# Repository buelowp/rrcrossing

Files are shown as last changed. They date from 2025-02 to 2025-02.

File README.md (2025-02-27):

# In track IR sensor for realistic crossing signals
This is a HW project based on a RPi Pico which will monitor 4 track sensors to determine which way a train is going, and then operate flashers and gates for one crossing. This actually works really well so far. But it needs more testing.

See a video in action at (https://youtu.be/GjpNI9cR6WQ)

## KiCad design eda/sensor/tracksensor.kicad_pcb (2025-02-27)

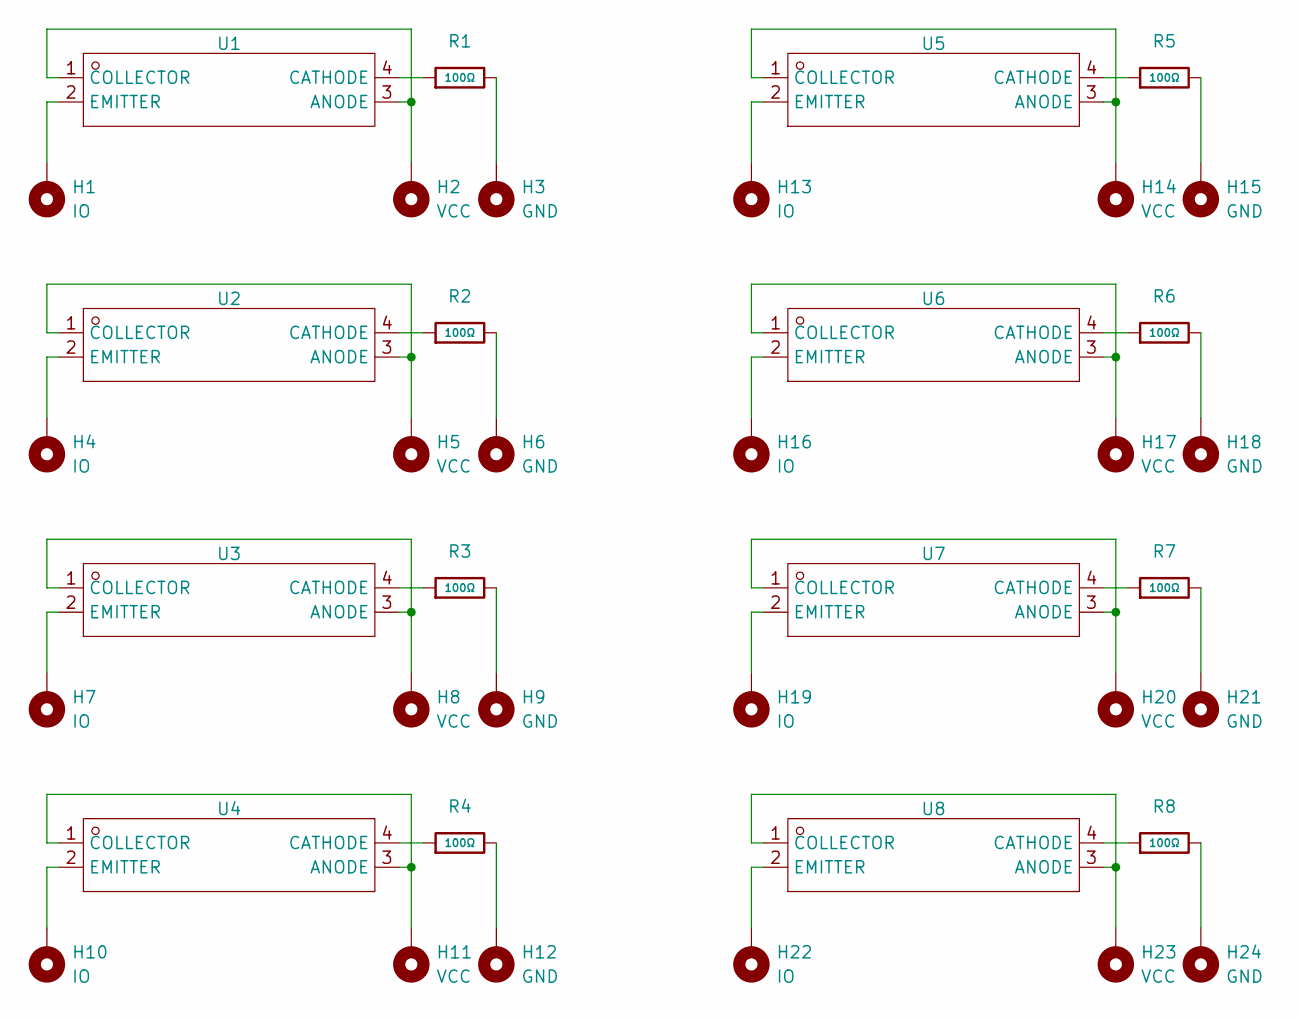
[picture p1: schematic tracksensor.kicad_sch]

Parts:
H1, H4, H7, H10, H13, H16, H19, H22: IO; TestPoint_Pad_1.5x1.5mm
H2, H5, H8, H11, H14, H17, H20, H23: VCC; TestPoint_Pad_1.5x1.5mm
H3, H6, H9, H12, H15, H18, H21, H24: GND; TestPoint_Pad_1.5x1.5mm
R1, R2, R3, R4, R5, R6, R7, R8: 100Ω; R_0402; Overload Voltage (Max) 50V; Tolerance ±1%; Part 0402WGF1000TCE; LCSC C25076
U1, U2, U3, U4, U5, U6, U7, U8: OPTO-SMD-4_ITR1204SR10A; Manufacturer Part ITR1204SR10A/TR(BY); LCSC Part Name 光电开关(ITR)

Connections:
unnamed: H3.1, R1.2
unnamed: H6.1, R2.2
unnamed: H9.1, R3.2
unnamed: H12.1, R4.2
unnamed: H15.1, R5.2
unnamed: H18.1, R6.2
unnamed: H21.1, R7.2
unnamed: H24.1, R8.2
unnamed: H2.1, U1.1 (COLLECTOR), U1.3 (ANODE)
unnamed: R1.1, U1.4 (CATHODE)
unnamed: H1.1, U1.2 (EMITTER)
unnamed: H5.1, U2.1 (COLLECTOR), U2.3 (ANODE)
unnamed: R2.1, U2.4 (CATHODE)
unnamed: H4.1, U2.2 (EMITTER)
unnamed: H8.1, U3.1 (COLLECTOR), U3.3 (ANODE)
unnamed: R3.1, U3.4 (CATHODE)
unnamed: H7.1, U3.2 (EMITTER)
unnamed: H11.1, U4.1 (COLLECTOR), U4.3 (ANODE)
unnamed: R4.1, U4.4 (CATHODE)
unnamed: H10.1, U4.2 (EMITTER)
unnamed: H14.1, U5.1 (COLLECTOR), U5.3 (ANODE)
unnamed: R5.1, U5.4 (CATHODE)
unnamed: H13.1, U5.2 (EMITTER)
unnamed: H17.1, U6.1 (COLLECTOR), U6.3 (ANODE)
unnamed: R6.1, U6.4 (CATHODE)
unnamed: H16.1, U6.2 (EMITTER)
unnamed: H20.1, U7.1 (COLLECTOR), U7.3 (ANODE)
unnamed: R7.1, U7.4 (CATHODE)
unnamed: H19.1, U7.2 (EMITTER)
unnamed: H23.1, U8.1 (COLLECTOR), U8.3 (ANODE)
unnamed: R8.1, U8.4 (CATHODE)
unnamed: H22.1, U8.2 (EMITTER)

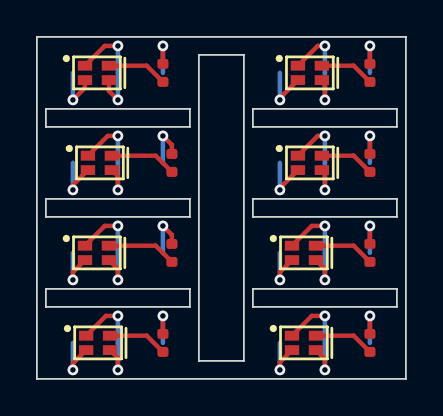
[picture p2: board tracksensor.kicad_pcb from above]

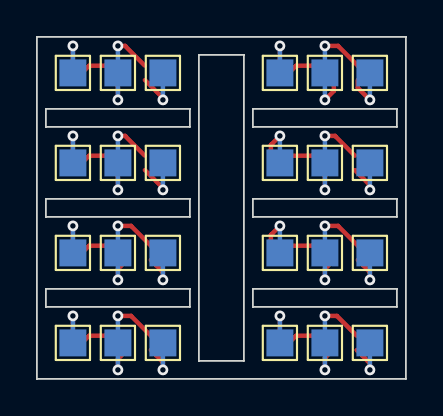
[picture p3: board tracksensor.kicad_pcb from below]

Board: 2 copper layers, 20.5 x 19.0 mm, 40 parts (24 on the bottom side), 32 nets.

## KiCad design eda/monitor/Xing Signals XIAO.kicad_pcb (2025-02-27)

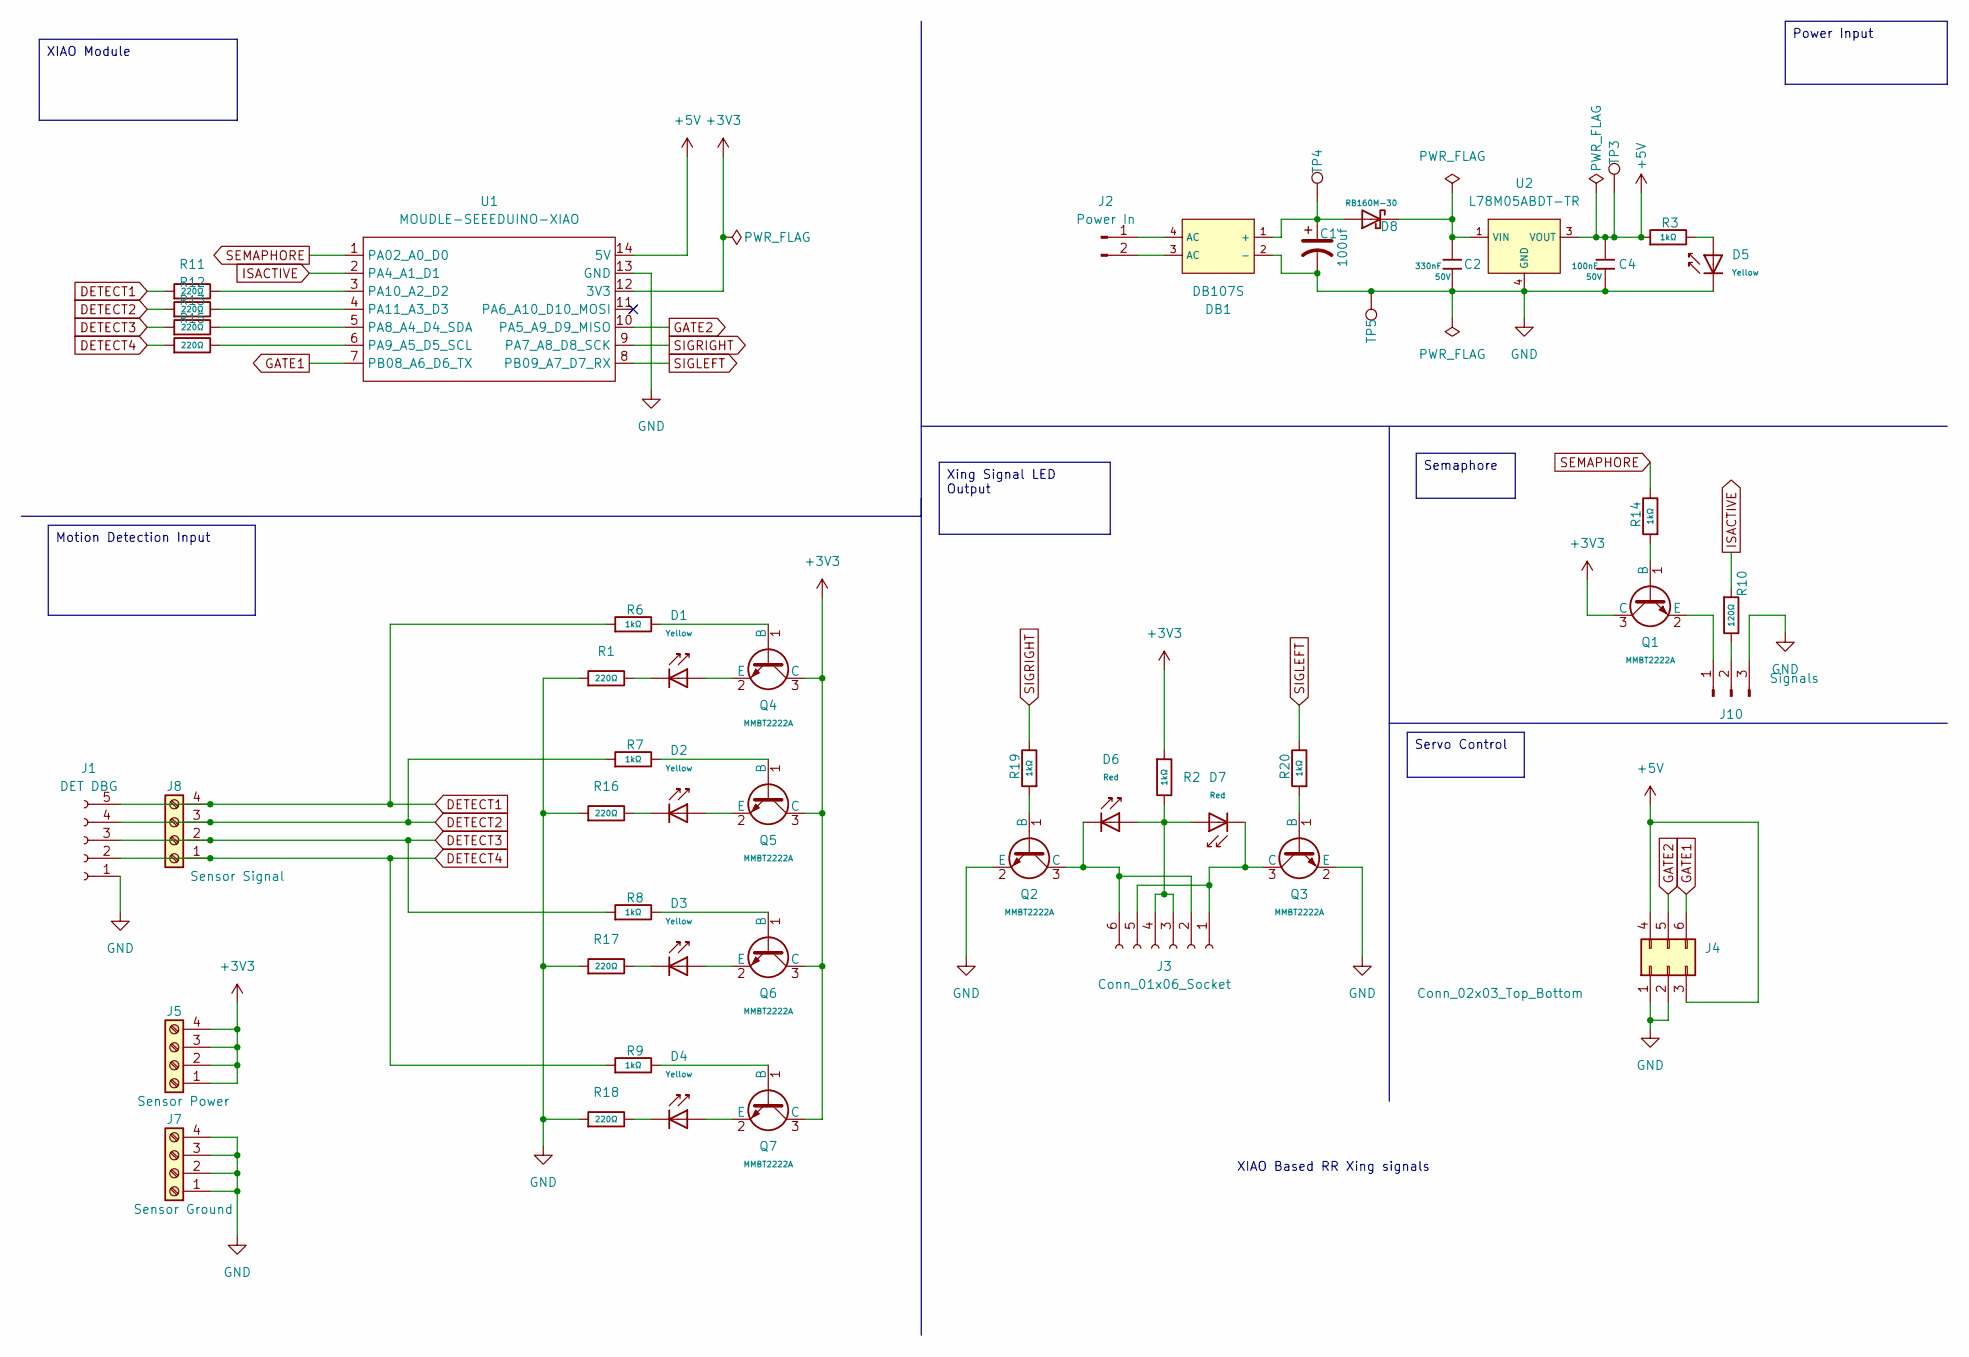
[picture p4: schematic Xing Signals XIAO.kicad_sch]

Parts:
C1: 100uf; CP_Radial_D5.0mm_P2.50mm
C2: 330nF; C_0805; Voltage Rated 50V; Tolerance ±10%; Part 0805B334K500NT; LCSC C1740
C4: 100nF; C_0603; Voltage Rated 50V; Tolerance ±10%; Part CC0603KRX7R9BB104; LCSC C14663
D1, D2, D3, D4, D5: Yellow; D_0603; Part 19-213/Y2C-CQ2R2L/3T(CY); LCSC C72038
D6, D7: Red; D_0603; Part KT-0603R; LCSC C2286
D8: RB160M-30; D_SOD-123; Forward Voltage (Vf@If) 480mV@1A; Reverse Voltage (Vr) 30V; Part RB160M-30; LCSC C7502715
DB1: DB107S; DBS_L8.2-W6.4-P5.10-LS10.0-BL; Reverse Voltage (Vr) 1kV; Forward Voltage (Vf@If) 1.1V@1A; Part DB107S; LCSC C5377
J1: DET DBG; PinHeader_1x05_P2.54mm_Vertical
J2: Power In; Molex_KK-396_A-41791-0002_1x02_P3.96mm_Vertical
J3: Conn_01x06_Socket; PinHeader_1x06_P2.54mm_Vertical
J4: Conn_02x03_Top_Bottom; PinHeader_2x03_P2.54mm_Vertical
J5: Sensor Power; PinHeader_1x04_P2.54mm_Vertical
J7: Sensor Ground; PinHeader_1x04_P2.54mm_Vertical
J8: Sensor Signal; PinHeader_1x04_P2.54mm_Vertical
J10: Signals; PinHeader_1x03_P2.54mm_Vertical
Q1, Q2, Q3, Q4, Q5, Q6, Q7: MMBT2222A; Q_SOT-23; Part MMBT2222A; LCSC C7420351
R1, R11, R12, R13, R15, R16, R17, R18: 220Ω; R_0402; Overload Voltage (Max) 50V; Tolerance ±1%; Part 0402WGF2200TCE; LCSC C25091
R2: 1kΩ; R_1206; Overload Voltage (Max) 200V; Tolerance ±1%; Part 1206W4F1001T5E; LCSC C4410
R3, R6, R7, R8, R9, R14, R19, R20: 1kΩ; R_0402; Overload Voltage (Max) 50V; Tolerance ±1%; Part 0402WGF1001TCE; LCSC C11702
R10: 120Ω; R_0402; Overload Voltage (Max) 50V; Tolerance ±1%; Part 0402WGF1200TCE; LCSC C25079
TP3, TP4, TP5: +5V; TestPoint_Pad_2.0x2.0mm
U1: MOUDLE-SEEEDUINO-XIAO; MOUDLE14P-2.54-21X17.8MM
U2: L78M05ABDT-TR; TO-252-2_L6.5-W6.1-P4.58-LS10.0-TL; Output Voltage 5V; Part L78M05ABDT-TR; LCSC C58069

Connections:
+3V3: J5.1, J5.2, J5.3, J5.4, Q1.3 (C), Q4.3 (C), Q5.3 (C), Q6.3 (C), Q7.3 (C), R2.1, U1.12 (3V3)
+5V: C4.1, J4.3, J4.4, R3.1, TP3.1, U1.14 (5V), U2.3 (VOUT)
DETECT1: J1.5, J8.4, R6.1, R11.1
DETECT2: J1.4, J8.3, R7.1, R12.1
DETECT3: J1.3, J8.2, R8.1, R13.1
DETECT4: J1.2, J8.1, R9.1, R15.1
GATE1: J4.6, U1.7 (PB08_A6_D6_TX)
GATE2: J4.5, U1.10 (PA5_A9_D9_MISO)
GND: C1.2, C2.2, C4.2, D5.1, DB1.2 (-), J1.1, J4.1, J4.2, J7.1, J7.2, J7.3, J7.4, J10.3, Q2.2 (E), Q3.2 (E), R1.1, R16.1, R17.1, R18.1, TP5.1, U1.13 (GND), U2.4 (GND); also elsewhere on the board
ISACTIVE: R10.1, U1.2 (PA4_A1_D1)
unnamed: D1.1, R1.2
unnamed: D2.1, R16.2
unnamed: D3.1, R17.2
unnamed: D4.1, R18.2
unnamed: D5.2, R3.2
unnamed: C1.1, D8.2, DB1.1 (+), TP4.1
unnamed: DB1.4 (AC), J2.1
unnamed: DB1.3 (AC), J2.2
unnamed: D7.1, J3.1, J3.5, Q3.3 (C)
unnamed: D6.1, J3.2, J3.6, Q2.3 (C)
unnamed: D6.2, D7.2, J3.3, J3.4, R2.2
unnamed: J10.1, Q1.2 (E)
unnamed: J10.2, R10.2
unnamed: Q1.1 (B), R14.1
unnamed: Q2.1 (B), R19.1
unnamed: Q3.1 (B), R20.1
unnamed: Q4.1 (B), R6.2
unnamed: D1.2, Q4.2 (E)
unnamed: Q5.1 (B), R7.2
unnamed: D2.2, Q5.2 (E)
unnamed: Q6.1 (B), R8.2
unnamed: D3.2, Q6.2 (E)
unnamed: Q7.1 (B), R9.2
unnamed: D4.2, Q7.2 (E)
unnamed: R13.2, U1.5 (PA8_A4_D4_SDA)
unnamed: R15.2, U1.6 (PA9_A5_D5_SCL)
unnamed: R11.2, U1.3 (PA10_A2_D2)
unnamed: R12.2, U1.4 (PA11_A3_D3)
unnamed: C2.1, D8.1, U2.1 (VIN)
SEMAPHORE: R14.2, U1.1 (PA02_A0_D0)
SIGLEFT: R20.2, U1.8 (PB09_A7_D7_RX)
SIGRIGHT: R19.2, U1.9 (PA7_A8_D8_SCK)

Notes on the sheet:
XIAO Based RR Xing signals
Xing Signal LED Output
Motion Detection Input
Servo Control
XIAO Module
Semaphore
Power Input

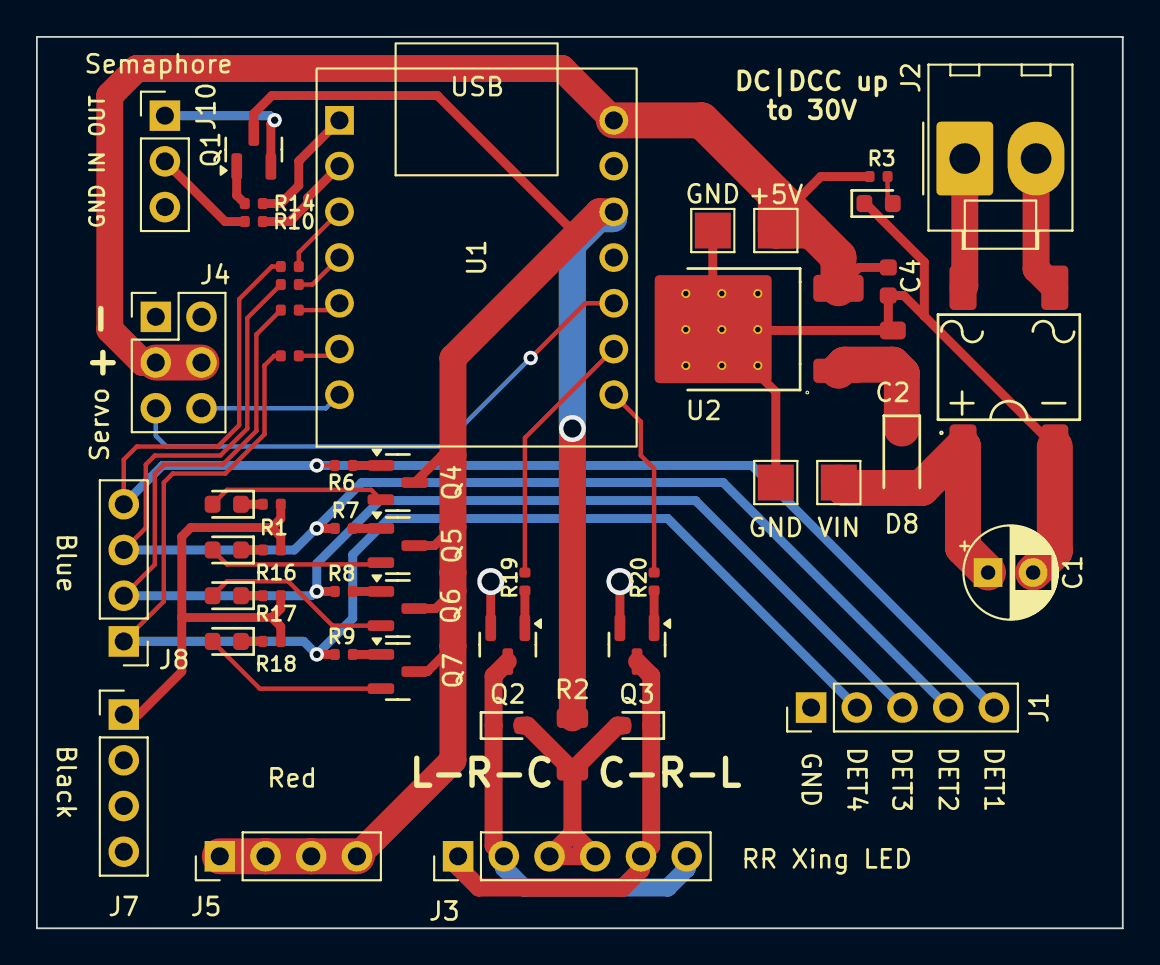
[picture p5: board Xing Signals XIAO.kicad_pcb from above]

Board: 2 copper layers, 60.3 x 49.5 mm, 51 parts (0 on the bottom side), 42 nets.

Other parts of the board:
TP1: GND; TestPoint_Pad_2.0x2.0mm

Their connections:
GND: TP1.1; also elsewhere on the board

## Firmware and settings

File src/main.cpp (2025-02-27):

#include <stdio.h>
#include "pico/stdlib.h"
#include "pico/multicore.h"
#include "ws2812.h"
#include "Servo.h"
#include "statemachine.h"

#define APP_ID          33

#define SEMAPHORE       27
#define SIBLING_ACTIVE        26
#define LED_R           17
#define LED_G           16
#define LED_B           25

#define SENSOR_EAST_ENTRY        28
#define SENSOR_WEST_EXIT        29
#define SENSOR_EAST_EXIT        6
#define SENSOR_WEST_ENTRY        7

#define NORTH_GATE          0
#define SOUTH_GATE          4

#define GATE_DOWN       0
#define GATE_UP         90

#define SIG_LEFT        1
#define SIG_RIGHT       2

bool g_cancelSignals;
bool g_localEvent;
int g_whichSignal;
int g_gateAngle;
int g_gateTarget;
Servo servo1;
Servo servo2;
repeating_timer_t g_activeSignalTimer;
repeating_timer_t g_activeGateTimer;
StateMachine sm;

bool signals_active(repeating_timer_t *rt)
{
    if (g_cancelSignals) {
        g_cancelSignals = false;
        gpio_put(SIG_LEFT, false);
        gpio_put(SIG_RIGHT, false);
        return false;
    }

    switch (g_whichSignal) {
        case SIG_LEFT:
            g_whichSignal = SIG_RIGHT;
            gpio_put(SIG_LEFT, true);
            gpio_put(SIG_RIGHT, false);
            break;
        case SIG_RIGHT:
            g_whichSignal = SIG_LEFT;
            gpio_put(SIG_LEFT, false);
            gpio_put(SIG_RIGHT, true);
            break;
    }
    return true;
}

void trigger_event(uint gpio, uint32_t event_mask)
{
    switch (gpio) {
        case SENSOR_EAST_ENTRY:
            if (event_mask == GPIO_IRQ_EDGE_RISE) {
                g_localEvent = true;
                sm.handleEvent(StateMachine::events::EASTBOUND);
            }
            break;
        case SENSOR_WEST_ENTRY:
            if (event_mask == GPIO_IRQ_EDGE_RISE) {
                g_localEvent = true;
                sm.handleEvent(StateMachine::events::WESTBOUND);
            }
            break;
        case SENSOR_WEST_EXIT:
            if (event_mask == GPIO_IRQ_EDGE_FALL)
                sm.handleEvent(StateMachine::events::LEAVINGWESTBOUND);
            break;
        case SENSOR_EAST_EXIT:
            if (event_mask == GPIO_IRQ_EDGE_FALL)
                sm.handleEvent(StateMachine::events::LEAVINGEASTBOUND);
            break;
        case SIBLING_ACTIVE:
            if (!g_localEvent) {
                if (event_mask == GPIO_IRQ_EDGE_RISE) {
                    sm.handleEvent(StateMachine::events::SIBLINGACTIVE);
                }
                else {
                    sm.handleEvent(StateMachine::events::SIBLINGINACTIVE);
                }
            }
            break;
    }
}

void setup_gpio()
{
    printf("Initializing gpio.\n");

    gpio_init(SEMAPHORE);
    gpio_init(SIBLING_ACTIVE);
    gpio_init(LED_R);
    gpio_init(LED_G);
    gpio_init(LED_B);
    gpio_init(SENSOR_EAST_ENTRY);
    gpio_init(SENSOR_WEST_EXIT);
    gpio_init(SENSOR_EAST_EXIT);
    gpio_init(SENSOR_WEST_ENTRY);
    gpio_init(SIG_LEFT);
    gpio_init(SIG_RIGHT);

    gpio_set_dir(SEMAPHORE, GPIO_OUT);

    gpio_set_dir(LED_R, GPIO_OUT);
    gpio_set_dir(LED_G, GPIO_OUT);
    gpio_set_dir(LED_B, GPIO_OUT);
    gpio_set_dir(SENSOR_EAST_ENTRY, GPIO_IN);
    gpio_set_dir(SENSOR_WEST_EXIT, GPIO_IN);
    gpio_set_dir(SENSOR_EAST_EXIT, GPIO_IN);
    gpio_set_dir(SENSOR_WEST_ENTRY, GPIO_IN);
    gpio_set_dir(SIG_LEFT, GPIO_OUT);
    gpio_set_dir(SIG_RIGHT, GPIO_OUT);
    gpio_set_dir(SIBLING_ACTIVE, GPIO_IN);

    gpio_pull_down(SENSOR_EAST_ENTRY);
    gpio_pull_down(SENSOR_WEST_EXIT);
    gpio_pull_down(SENSOR_EAST_EXIT);
    gpio_pull_down(SENSOR_WEST_ENTRY);
    gpio_pull_down(SIBLING_ACTIVE);

    gpio_set_irq_enabled_with_callback(SENSOR_EAST_ENTRY, GPIO_IRQ_EDGE_RISE|GPIO_IRQ_EDGE_FALL, true, trigger_event);
    gpio_set_irq_enabled_with_callback(SENSOR_WEST_EXIT, GPIO_IRQ_EDGE_RISE|GPIO_IRQ_EDGE_FALL, true, trigger_event);
    gpio_set_irq_enabled_with_callback(SENSOR_EAST_EXIT, GPIO_IRQ_EDGE_RISE|GPIO_IRQ_EDGE_FALL, true, trigger_event);
    gpio_set_irq_enabled_with_callback(SENSOR_WEST_ENTRY, GPIO_IRQ_EDGE_RISE|GPIO_IRQ_EDGE_FALL, true, trigger_event);
    gpio_set_irq_enabled_with_callback(SIBLING_ACTIVE, GPIO_IRQ_EDGE_RISE|GPIO_IRQ_EDGE_FALL, true, trigger_event);

    servo1.attach(NORTH_GATE);
    servo2.attach(SOUTH_GATE);
    servo1.write(GATE_UP);
    servo2.write(GATE_UP);
}

void led_control(bool state)
{
    if (state) {
        g_cancelSignals = false;
        add_repeating_timer_ms(1000, signals_active, NULL, &g_activeSignalTimer);
    }
    else {
        g_cancelSignals = true;
    }
}

bool gate_action(repeating_timer_t *rt)
{
    if (g_gateTarget == GATE_UP) {
        if (++g_gateAngle <= GATE_UP) {
            servo1.write(g_gateAngle);
            servo2.write(g_gateAngle);
            return true;
        }
        else {
            sm.handleEvent(StateMachine::events::GATERAISED);
        }
    }
    else if (g_gateTarget == GATE_DOWN) {
        if (--g_gateAngle >= GATE_DOWN) {
            servo1.write(g_gateAngle);
            servo2.write(g_gateAngle);
            return true;
        }
        else {
            sm.handleEvent(StateMachine::events::GATELOWERED);
        }
    }

    if (g_gateAngle == GATE_DOWN - 1)
        g_gateAngle = GATE_DOWN;

    if (g_gateAngle == GATE_UP + 1)
        g_gateAngle = GATE_UP;

    return false;
}

void semaphore_control(bool state)
{
    printf("%s: state:%s\n", __PRETTY_FUNCTION__, state ? "true" : "false");
    gpio_put(SEMAPHORE, state);
}

void gate_control(bool state)
{
    printf("%s: Setting target to %d\n", state);

    if (state) {
        g_gateTarget = GATE_DOWN;
    }
    else {
        g_gateTarget = GATE_UP;
    }
    add_repeating_timer_ms(125, gate_action, NULL, &g_activeGateTimer);
}

int main() 
{
    bool triggerEvent = false;
    stdio_init_all();
    sleep_ms(5000);
    setup_gpio();
    sm.setCallbacks(led_control, gate_control, semaphore_control);
    
    printf("%s: Starting main for APP_ID: %d\n", __PRETTY_FUNCTION__, APP_ID);

    g_whichSignal = SIG_LEFT;
    g_cancelSignals = false;
    g_gateAngle = GATE_UP;
    g_localEvent = false;
    alarm_pool_create(0, 2);

    while (1) {
        tight_loop_contents();
    }

    return 0;
}

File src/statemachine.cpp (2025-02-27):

#include "statemachine.h"

static int64_t enable_semaphore(alarm_id_t id, void *user_data)
{
    printf("%s: Turning on Semaphore pin\n", __PRETTY_FUNCTION__);
    StateMachine *sm = (StateMachine*)user_data;
    sm->enableSemaphore();
    return 0;
}

static int64_t alarm_callback(alarm_id_t id, void *user_data)
{
    StateMachine *sm = (StateMachine*)user_data;

    printf("%s: Handling alarm %d, and still active is %d\n", __PRETTY_FUNCTION__, id, sm->stillActive());
    if (sm->stillActive()) {
        return ONE_SECOND;
    }
    else {
        sm->handleEvent(StateMachine::events::RAISEGATE);
    }
    sm->setAlarmHandleValue(INVALID_ALARM);
    return 0;
}

StateMachine::StateMachine()
{
    m_state = OFF;
    m_isActive = false;
    m_direction = STOPPED;
    m_localSensorActive = false;
    m_endAlarm = INVALID_ALARM;
    m_continueWaitingForExit = false;
    setLedColor(false, false, false);
    m_disabled = false;
}

StateMachine::StateMachine(std::function<void(bool)> lightSwitch, std::function<void(bool)> gateControl, std::function<void(bool)> semaphoreControl)
{
    if (lightSwitch)
        m_lightSwitch = lightSwitch;

    if (gateControl)
        m_gateControl = gateControl;

    if (semaphoreControl)
        m_semControl = semaphoreControl;

    m_state = OFF;
    m_isActive = false;
    m_direction = STOPPED;
    m_localSensorActive = false;
    m_endAlarm = INVALID_ALARM;
    m_continueWaitingForExit = false;
    setLedColor(false, false, false);
    m_disabled = false;
}

StateMachine::~StateMachine()
{
}

void StateMachine::setLedColor(bool red, bool green, bool blue)
{
    gpio_put(colors::red, !red);
    gpio_put(colors::green, !green);
    gpio_put(colors::blue, !blue);
}

void StateMachine::setAlarmHandleValue(int32_t value) 
{
    m_endAlarm = value;
}

bool StateMachine::stillActive()
{
    return m_remoteSensorActive;
}

void StateMachine::setCallbacks(std::function<void(bool)> lightSwitch, std::function<void(bool)> gateControl, std::function<void(bool)> semaphoreControl)
{
    if (lightSwitch)
        m_lightSwitch = lightSwitch;

    if (gateControl)
        m_gateControl = gateControl;

    if (semaphoreControl)
        m_semControl = semaphoreControl;

    setLedColor(false, true, false);   
}

void StateMachine::raiseGate()
{
    printf("%s\n", __PRETTY_FUNCTION__);
    m_gateControl(false);
    m_semControl(false);
    m_state = SIGNALGATEUP;
    setLedColor(true, true, false);
}

void StateMachine::turnOn()
{
    printf("%s\n", __PRETTY_FUNCTION__);
    m_state = ON;
    m_lightSwitch(true);
    m_gateControl(true);
    m_semControl(true);
    if (m_remoteSensorActive)
        setLedColor(false, false, true);
    else
        setLedColor(true, false, false);
}

void StateMachine::turnOff()
{
    printf("%s\n", __PRETTY_FUNCTION__);
    m_lightSwitch(false);
    m_state = OFF;
    m_direction = STOPPED;
    setLedColor(true, false, false);
}

void StateMachine::handleEvent(events event)
{
    if (m_disabled) {
        return;
    }

    switch (event) {
        case EASTBOUND:
            printf("%s: EASTBOUND: %d\n", __PRETTY_FUNCTION__, m_state);
            if (m_state == OFF) {
                m_localSensorActive = true;
                m_direction = EAST;
                turnOn();
            }
            break;
        case WESTBOUND:
            printf("%s: WESTBOUND: %d\n", __PRETTY_FUNCTION__, m_state);
            if (m_state == OFF) {
                m_localSensorActive = true;
                m_direction = WEST;
                turnOn();
            }
            break;
        case SIBLINGACTIVE:
            printf("%s: SIBLINGACTIVE: state:%d, remote:%s\n", __PRETTY_FUNCTION__, m_state, m_remoteSensorActive ? "true" : "false");
            m_remoteSensorActive = true;
            if (m_state == OFF) {
                turnOn();
            }
            break;
        case LEAVINGEASTBOUND:
            printf("%s: LEAVINGEASTBOUND: direction:%d, state:%d: sibling:%s\n", __PRETTY_FUNCTION__, m_direction, m_state, m_remoteSensorActive ? "true" : "false");
            if (m_remoteSensorActive) 
                break;

            if (m_direction == EAST && m_state == ON) {
                if (m_endAlarm != INVALID_ALARM) {
                    if (cancel_alarm(m_endAlarm)) {
                        printf("%s: Canceled alarm %d\n", m_endAlarm);
                    }
                }
                m_endAlarm = add_alarm_in_us(FIVE_SECONDS, alarm_callback, (void*)this, true);
            }
            break;
        case LEAVINGWESTBOUND:
            printf("%s: LEAVINGWESTBOUND: direction:%d, state:%d: sibling:%s\n", __PRETTY_FUNCTION__, m_direction, m_state, m_remoteSensorActive ? "true" : "false");
            if (m_remoteSensorActive)
                break;

            if (m_direction == WEST && m_state == ON) {
                if (m_endAlarm != INVALID_ALARM) {
                    if (cancel_alarm(m_endAlarm)) {
                        printf("%s: Canceled alarm %d\n", __PRETTY_FUNCTION__, m_endAlarm);
                        m_endAlarm = add_alarm_in_us(FIVE_SECONDS, alarm_callback, (void*)this, true);
                    }
                }
                m_endAlarm = add_alarm_in_us(FIVE_SECONDS, alarm_callback, (void*)this, true);
            }
            break;
        case SIBLINGINACTIVE:
            printf("%s: SIBLINGINACTIVE: state:%d, active:%d\n", __PRETTY_FUNCTION__, m_state, m_remoteSensorActive);
            if (m_remoteSensorActive) {
                if (m_state == ON) {
                    raiseGate();
                }
                m_remoteSensorActive = false;
            }
            break;
        case RAISEGATE:
            printf("%s: RAISEGATE\n", __PRETTY_FUNCTION__);
            raiseGate();
            break;
        case GATERAISED:
            printf("%s: GATERAISED\n", __PRETTY_FUNCTION__);
            turnOff();
            break;
        case LOWERGATE:
            printf("%s: LOWERGATE\n", __PRETTY_FUNCTION__);
            break;
        case GATELOWERED:
            printf("%s: GATELOWERED\n", __PRETTY_FUNCTION__);
            break;
    }
}

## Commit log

2024-01-23 Initial commit
    * Doesn't work exactly right, but it's making progress
    [main.cpp, statemachine.cpp, ws2812.cpp]
2024-01-24 Fixes
    * Add LED control
    * Fixup of state machine a bit
    [main.cpp, statemachine.cpp]
2024-01-27 Fix and debug changes
    * Fixed a bug with the sibling handling
    * Updated and fixed some printf calls
    [main.cpp, statemachine.cpp]
2024-01-27 Add the PCB work
    [Xing Signals XIAO.kicad_pcb, Xing Signals XIAO.kicad_sch]
2024-02-06 Version 1.1 of the PCB
    [Xing Signals XIAO.kicad_pcb, Xing Signals XIAO.kicad_sch]
2024-02-07 Fixes to Version 1.1
    * Trace fixups
    * Components moved to better fit
    * Move the sensor screw terminals next to each other
    * Cleaned up the transistor layout for the sensor LED indicators
    * Servo pins are now 2x3
    [Xing Signals XIAO.kicad_pcb, Xing Signals XIAO.kicad_sch]
2024-02-08 More fixes, ordered V1.1
    * Added C3 to buffer the Servo current draw
    * More fixes for traces
    * Fixed TP2 to be VIN, not +12V
    [Xing Signals XIAO.kicad_pcb, Xing Signals XIAO.kicad_sch]
2024-02-08 Version 1.2
    * Fixed a clearance issue between J3 and C2
    * Moved D6 and D7 a bit closer to J3
    [Xing Signals XIAO.kicad_pcb, Xing Signals XIAO.kicad_sch]
2025-02-27 Updating this and will make it public.
    [Xing Signals XIAO.kicad_pcb, Xing Signals XIAO.kicad_sch]
2025-02-27 Adding the track sensor in KiCad
    [tracksensor.kicad_pcb, tracksensor.kicad_sch]
